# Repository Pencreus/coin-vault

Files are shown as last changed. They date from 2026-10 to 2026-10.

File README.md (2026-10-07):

# Coin Vault

3D-printable storage trays for copper bullion in Air-Tite capsules. Coins stand on
edge, face to face, in a curved cradle, and a sliding bookend keeps a part-full row
upright. Everything is parametric OpenSCAD and prints with no supports.

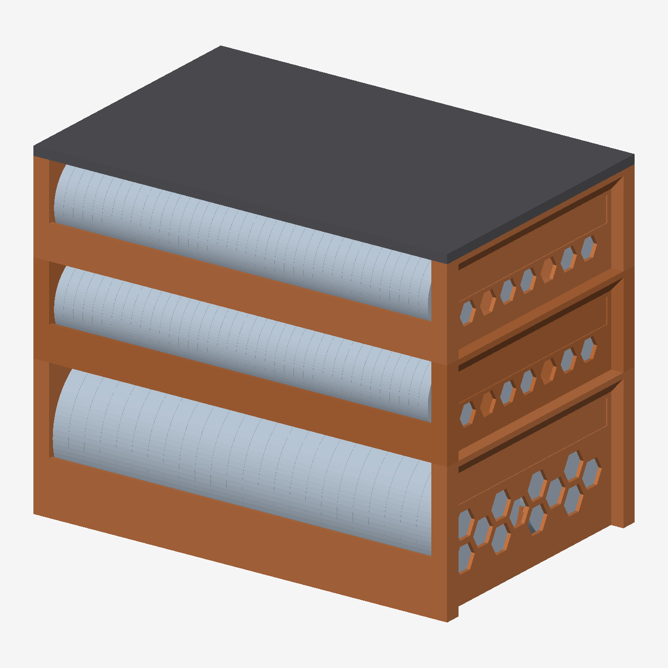
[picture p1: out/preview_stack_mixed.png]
Mixed stack: one 5 oz tray, two 1 oz trays, one lid


## Parts

| File | Holds | Size (mm) | PLA |
|---|---|---|---|
| `coin_vault_tray_Y63.stl` | 48 × 5 oz rounds in Air-Tite **Y63** (Ø71.37 × 8.9) | 233 × 151 × 77 | ~210 g |
| `coin_vault_tray_H39.stl` | 117 × 1 oz rounds in Air-Tite **H39** (Ø44.45 × 5.4) | 233 × 151 × 50 | ~175 g |
| `coin_vault_tray_NICKEL.stl` | 175 × Buffalo nickels in Ø25.5 capsules (5 rows) | 233 × 151 × 31.5 | ~155 g |
| `coin_vault_tray_HALF.stl` | 105 × half dollars in Ø35.3 capsules (3 rows) | 233 × 151 × 41 | ~165 g |
| `coin_vault_tray_MIXED.stl` | 35 nickels (front row) + 105 half dollars (3 rows) | 233 × 151 × 41 | ~170 g |
| `coin_vault_lid.stl` | caps any stack | 233 × 151 × 5 | ~95 g |
| `coin_vault_bookend_Y63.stl` / `_H39.stl` / `_NICKEL.stl` / `_HALF.stl` | one per part-full row | | 1–10 g |
| `slab_tray.stl` | 52 × 90 × 60 mm 5 oz slab capsules (7–8 mm thick), portrait | 233 × 151 × 55 | ~160 g |
| `slab_bookend.stl` | one per part-full row | | ~12 g |

Gram figures are estimates at 15% infill; your slicer has the final word. Nickel and half-dollar
counts assume 6 mm capsules; capsules stand face to face, so thinner ones simply fit more per row.

**Coin trays stack.** The 5 oz, 1 oz, nickel, half-dollar and mixed trays share one footprint
and corner-post pattern, so they mix freely in a stack under the same lid. Tapered pins on the posts
locate each tray, and each tray's floor closes the one below it. The slab tray is a
tray with carry handles and the same footprint. Sockets in its four corner feet take the coin
trays' pins, so it can sit on top of any coin tray in place of the lid. Nothing stacks on
top of it.

## Customizing

Open `coin_vault.scad` or `slab_tray.scad` in OpenSCAD and use **Window → Customizer**.
Keep `patterns.scad` in the same folder, because both files include it.

- `coin_vault.scad`: `capsule` (Y63 / H39 / NICKEL / HALF / MIXED), `part` (tray / lid / bookend / preview),
  rows and capsules per row (0 = as many as fit), clearances, end-wall opening pattern.
- `slab_tray.scad`: `footprint` (match the coin trays, or size from rows), `orientation`
  (portrait / landscape), `slab_t` (capsule thickness, default 8 mm), side and end wall heights.

Export with the Manifold backend (the default in current OpenSCAD).

## Strength

A full 5 oz tray holds about 8.7 kg. On a shelf the floor is supported everywhere. In a
stack, or when you lift it by the handles, the floor has to span about 217 mm between
the end walls. `sag_check.py` models that case conservatively: PLA long-term creep
modulus at E/3, sparse infill counted at 5% stiffness.

```
python sag_check.py Y63    # 5 oz: 0.96 mm worst case vs 1.85 mm clearance
python sag_check.py H39    # 1 oz: 0.73 mm worst case
python sag_check.py NICKEL # 0.66 mm;  HALF: 0.49 mm
```

These results set the design rules. Don't relax them to save filament:

- **Long walls stay solid.** Lattice openings in them made stacked sag 2.6× worse to
  save about 13 g.
- **The cradle floor is 3 mm thick at its lowest point.** At 1.2 mm the thin centre
  line acts as a hinge across the row.
- **Corner posts:** a 6-high stack of 5 oz trays stays at 4× their buckling margin.

## Printing

- PLA. It creeps less than PETG at room temperature. Keep it out of hot garages and
  attics, because PLA softens well below 60 °C.
- 15%+ infill (the cradle's stiffness depends on it), 0.2 mm layers, no supports.
- Print trays and the lid as modelled. Bookends print flat on their plate.
- End-wall openings are flat-top hexagons (short bridges only). Other patterns are in
  `patterns.scad`: diamond and teardrop are bridge-free, and X-brace is kept for
  reference only, since its triangle tops print badly.
- Store stacks on a solid shelf, not wire shelving.

## Files

- `coin_vault.scad`: stacking coin trays, lid, bookends
- `slab_tray.scad`: slab tray and bookend
- `patterns.scad`: shared wall-opening patterns
- `sag_check.py`: conservative stiffness check (numpy)
- `render.py`: tiny z-buffer STL preview renderer (numpy, trimesh, pillow)
- `out/`: exported STLs and preview images

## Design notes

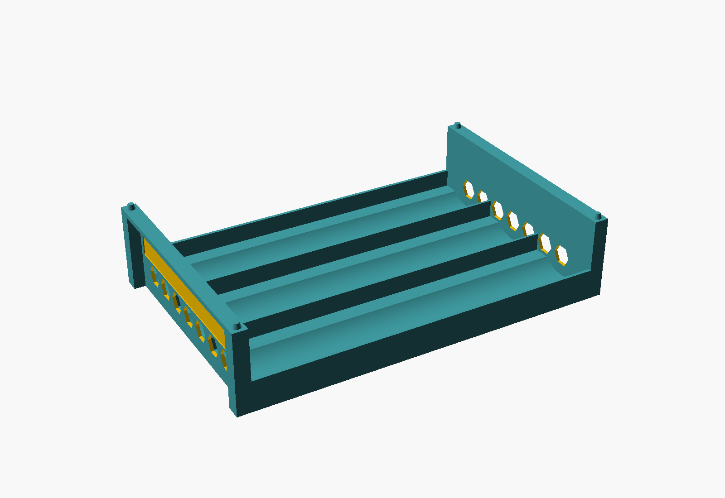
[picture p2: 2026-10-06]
out/preview_tray_H39.png

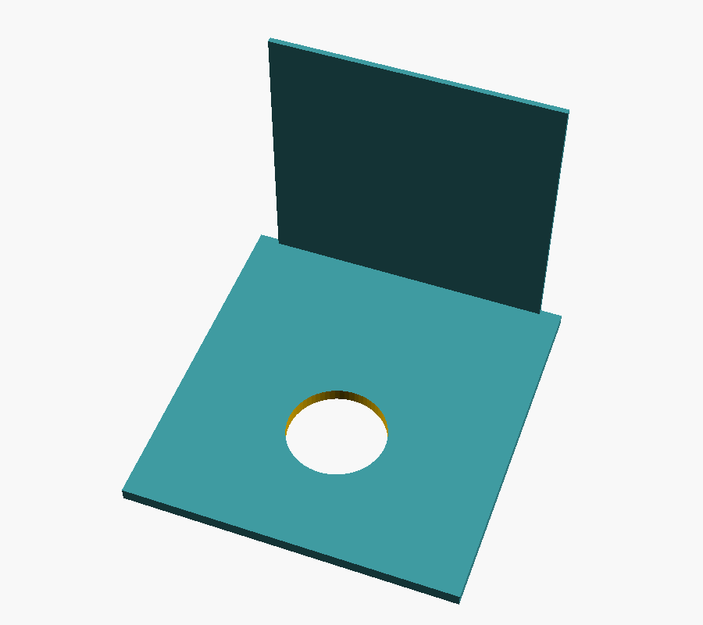
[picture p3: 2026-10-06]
out/preview_slab_bookend.png

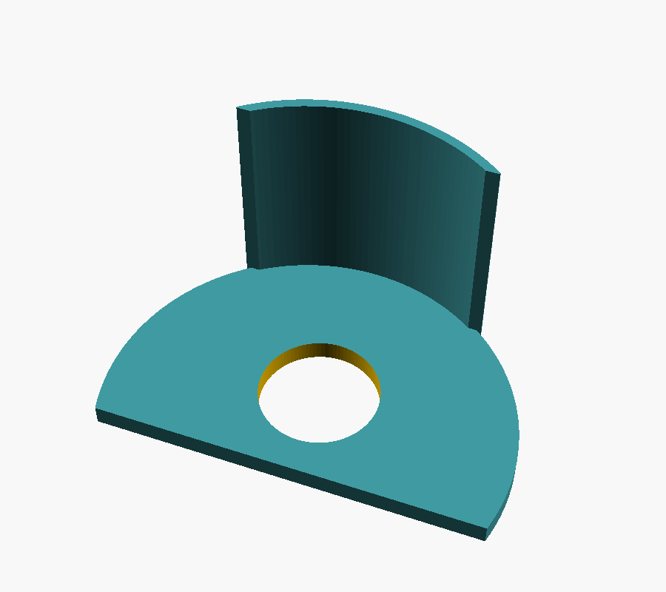
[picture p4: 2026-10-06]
out/preview_bookend_H39.png

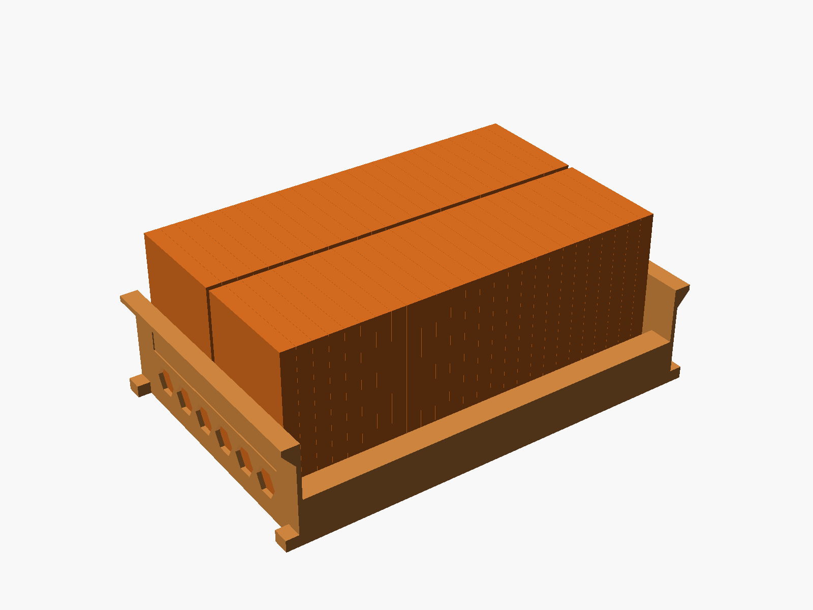
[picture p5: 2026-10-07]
out/preview_slab_loaded.png

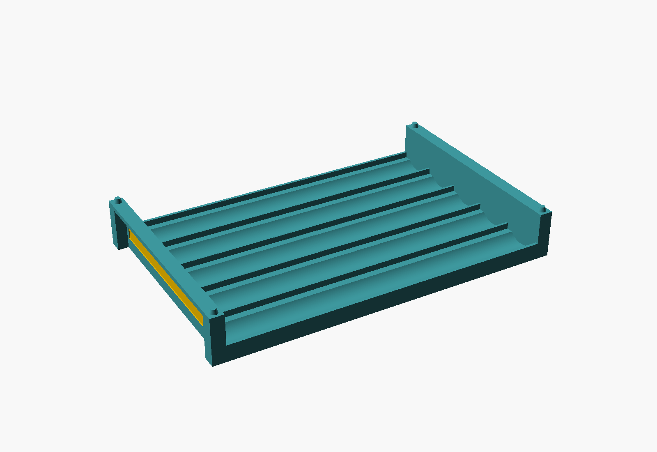
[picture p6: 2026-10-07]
out/preview_tray_NICKEL.png

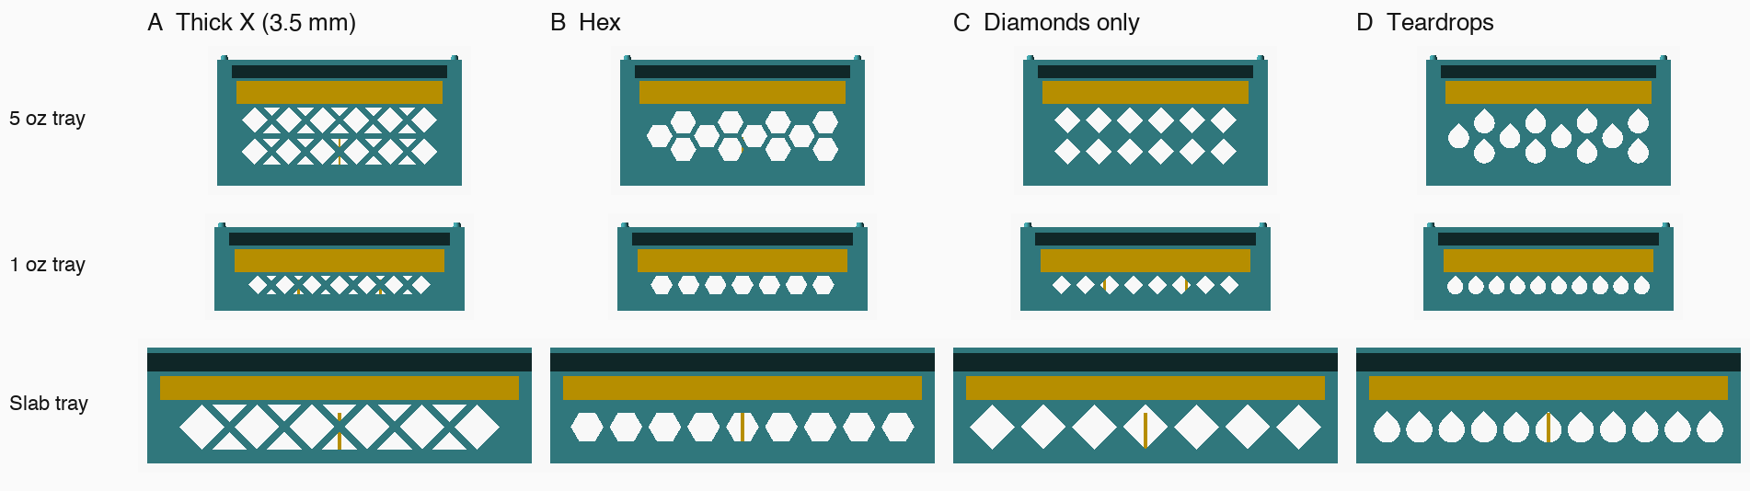
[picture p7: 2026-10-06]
out/pattern_compare.png

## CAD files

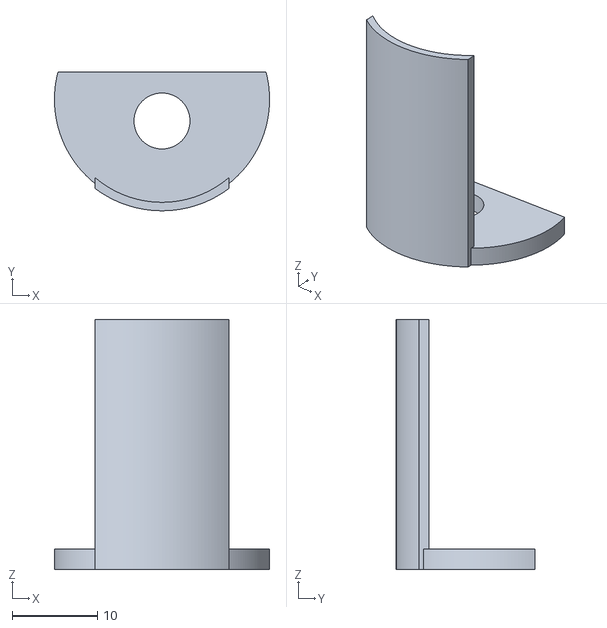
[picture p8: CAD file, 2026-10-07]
out/coin_vault_bookend_NICKEL.stl
25.3 x 16.3 x 29.4

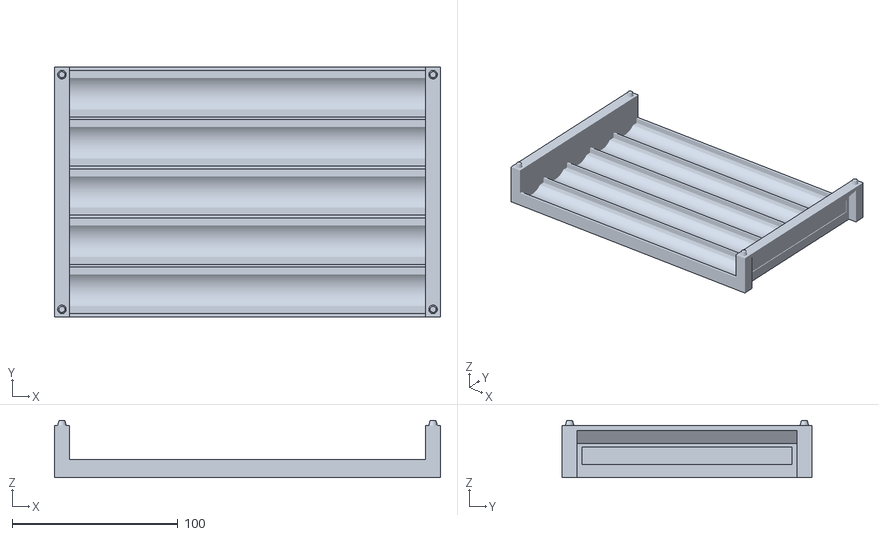
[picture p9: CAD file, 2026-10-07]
out/coin_vault_tray_NICKEL.stl
233.1 x 150.7 x 34.5

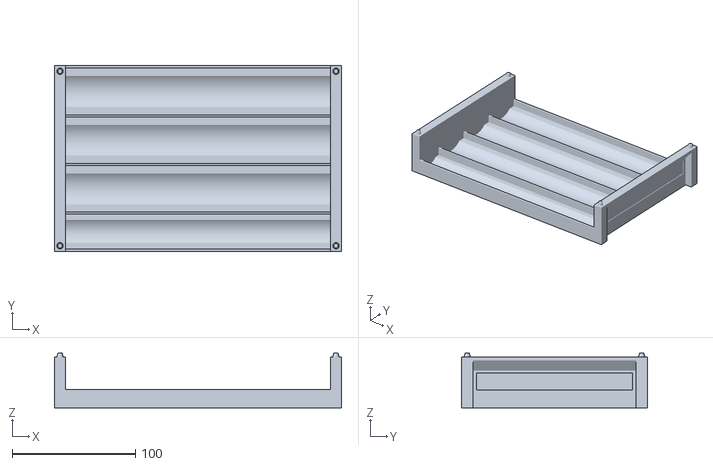
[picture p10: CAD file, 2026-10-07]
out/coin_vault_tray_MIXED.stl
233.1 x 150.7 x 44.3

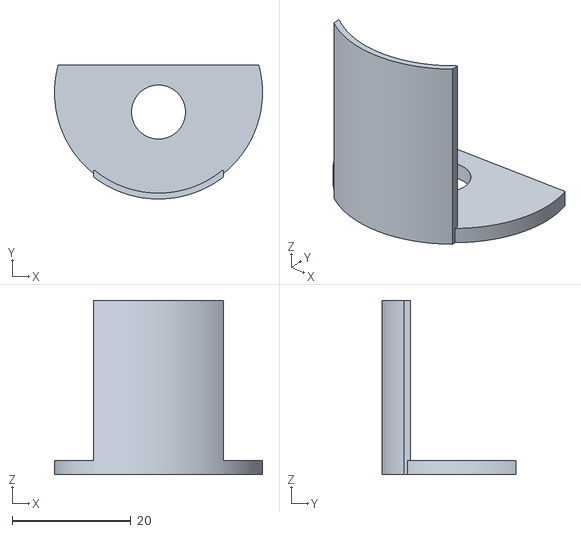
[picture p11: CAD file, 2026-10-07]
out/coin_vault_bookend_HALF.stl
35.1 x 22.6 x 29.4

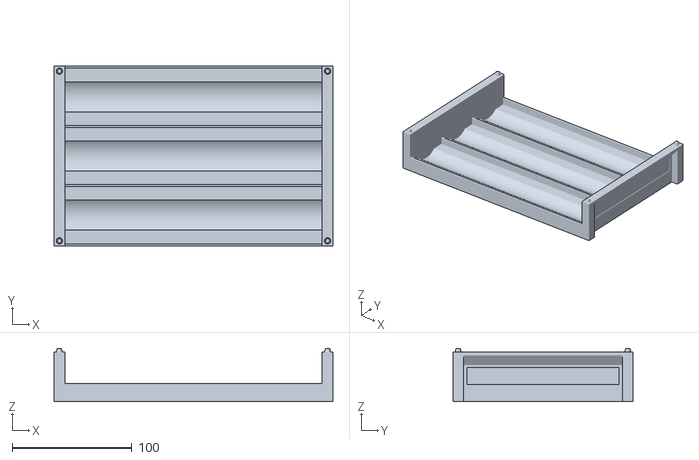
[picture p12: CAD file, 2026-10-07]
out/coin_vault_tray_HALF.stl
233.1 x 150.7 x 44.3

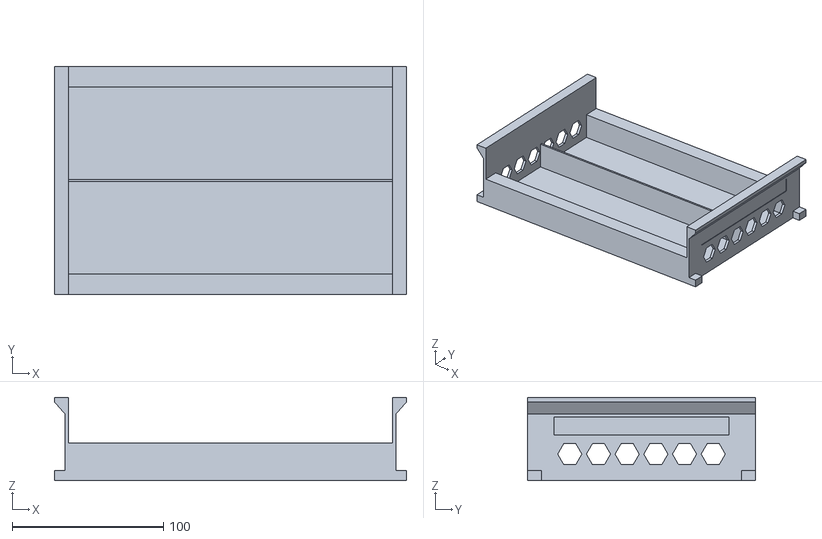
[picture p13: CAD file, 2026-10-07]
out/slab_tray.stl
233.1 x 150.7 x 55.0

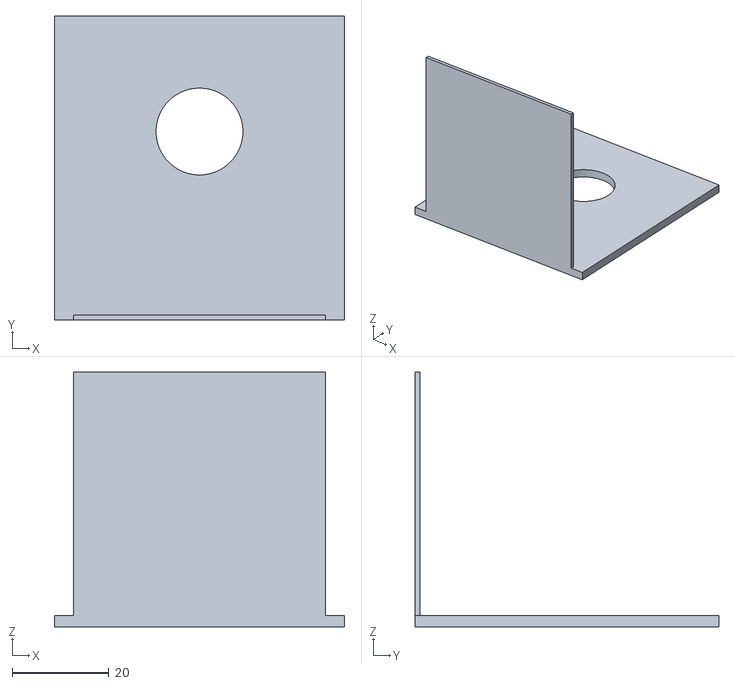
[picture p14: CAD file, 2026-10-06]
out/slab_bookend.stl
60.2 x 63.0 x 52.8

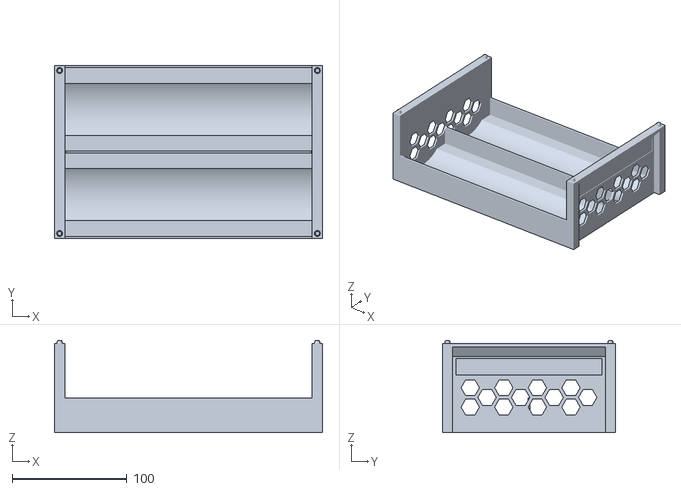
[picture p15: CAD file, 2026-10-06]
out/coin_vault_tray_Y63.stl
233.1 x 150.7 x 80.4

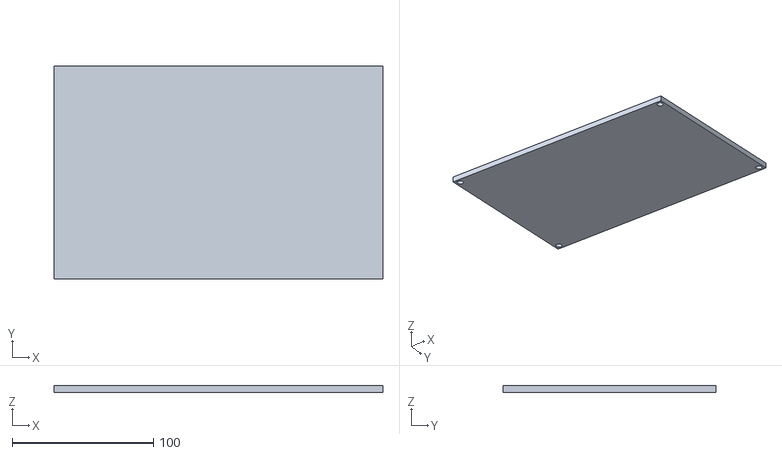
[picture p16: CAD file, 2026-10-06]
out/coin_vault_lid.stl
233.1 x 150.7 x 5.00

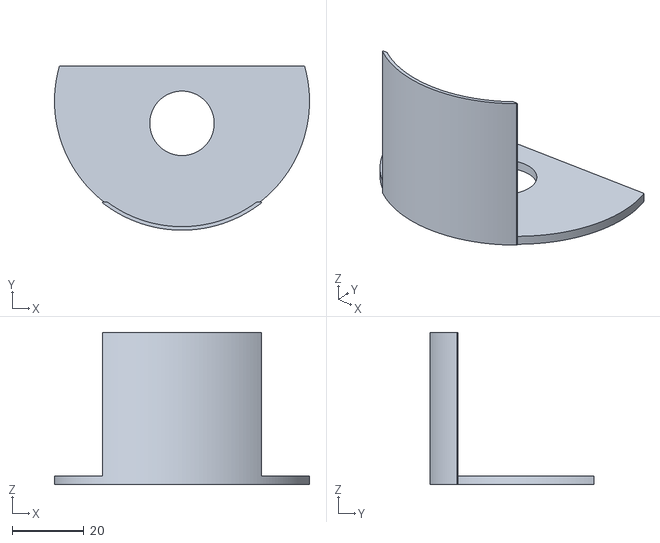
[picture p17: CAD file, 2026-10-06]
out/coin_vault_bookend_Y63.stl
71.2 x 45.9 x 42.5

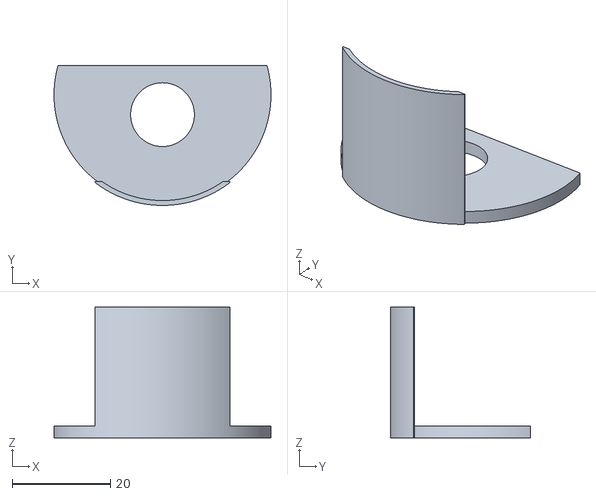
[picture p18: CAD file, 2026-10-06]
out/coin_vault_bookend_H39.stl
44.2 x 28.5 x 26.7

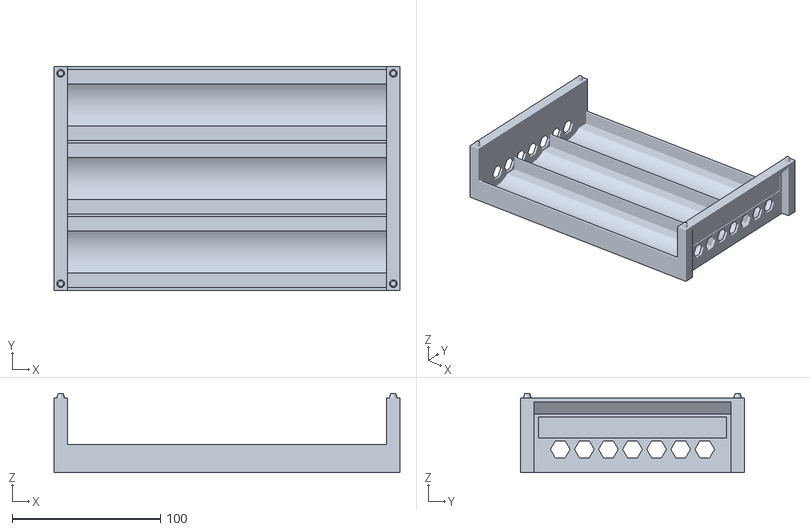
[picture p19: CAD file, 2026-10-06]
out/coin_vault_tray_H39.stl
233.1 x 150.7 x 53.4

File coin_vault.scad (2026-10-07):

// Coin Vault: stackable trays for Air-Tite capsules: Y63 (5 oz rounds) and H39 (1 oz).
// Every capsule type shares one footprint and post pattern, so 1 oz and 5 oz trays
// stack together under the same lid.
// Capsules stand on edge, face to face, in a curved cradle. A sliding bookend
// holds a part-full row upright. Trays stack on corner posts with tapered pins,
// and each tray's floor is the lid of the one below.
// Axes: X = along a row, Y = across rows, Z = up. Prints as modelled, no supports.

/* [Part] */
part = "tray"; // [tray, lid, bookend, preview_stack]

/* [Capsule] */
capsule = "Y63"; // [Y63:Y63 - 5 oz rounds, H39:H39 - 1 oz rounds, NICKEL:Nickel capsules (25.5 mm), HALF:Half dollar capsules (35.3 mm), MIXED:Mixed - 1 row of nickels + 3 rows of halves]

/* [Layout] */
footprint = "shared"; // [shared:Shared - stacks with every other tray, custom:Custom - sized from rows x per_row]
rows = 0;        // [0:1:6] 0 = as many as fit
per_row = 0;     // [0:1:45] 0 = as many as fit
row_clr = 1.5;   // minimum slack along a full row
clr_d = 1.2;     // row clearance, across the capsule diameter
top_clr = 3.0;   // gap above the capsule to the next tray's floor (sag margin)

/* [Structure] */
floor_t = 3.0;   // under the lowest point of the cradle. Do not thin: see sag_check.py
cradle_clr = 0.5;// cradle radius over the capsule radius
side = 2.0;      // long side walls
// side_h and cradle_h come from the capsule preset below
spine = 1.6;     // divider between rows
end_t = 2.0;     // end walls, full height
post = 9;        // square corner post
ledge_t = 3;     // handle ledge flange (45 deg gusset below)
label_d = 0.6;   // recessed label panel depth
lid_t = 5.0;     // flat slab; sockets are 3.5 deep, leaving a 1.5 mm roof over them

/* [Wall openings] */
end_pattern = "hex"; // [hex, diamond, teardrop, xbrace, solid] end walls (see patterns.scad)
web = 3.0;       // minimum material between openings
cell = 16;       // nominal opening size
wall_pattern = "solid"; // [solid, hex, diamond, teardrop, xbrace] long walls + spine. Openings here
                         // make a stacked tray sag ~2.6x more (sag_check.py) to save ~13 g: keep solid
strut = 2.0;     // solid band above the cradle before any opening
chord = 4;       // solid rail along the top of each wall
end_solid = 14;  // solid wall length next to each end (highest shear)
label_h = 14;    // label strip height, in the solid band under the ledge

/* [Bookend] */
book_t = 2.4;    // plate thickness
foot_t = 1.0;    // curved foot the capsules stand on

/* [Stacking pins] */
pin_h = 3;
pin_r0 = 2.6;
pin_r1 = 1.8;
sock_clr = 0.25;

/* [Hidden] */
include <patterns.scad>
$fn = 96;
eps = 0.01;

// Capsule presets. Air-Tite specs: Y63 = 71.37 OD x 8.9 closed; H39 = 44.45 OD x 5.4 closed.
//              cap_d  cap_t  side_h  cradle_h
PRESETS = [["Y63",    71.37, 8.9,  30,     8],
           ["H39",    44.45, 5.4,  19,     5],
           // Dad's generic capsules, measured: OD only. cap_t (6 mm) only sets the count and
           // preview: capsules stand face to face, so thinner ones just fit more per row.
           ["NICKEL", 25.5,  6.0,  11,     4],
           ["HALF",   35.3,  6.0,  15,     5],
           // MIXED: a row of nickels + 3 rows of halves (lanes below). Values are the halves'
           // (the tallest capsule sets the tray height and end walls).
           ["MIXED",  35.3,  6.0,  15,     5]];
P = PRESETS[search([capsule], PRESETS)[0]];
cap_d = P[1];
cap_t = P[2];
side_h = P[3];   // ~42% of the capsule: low enough to grip a rim from the side
cradle_h = P[4];

// The shared footprint is the 5 oz tray's: 2 rows x 24 Y63 capsules.
FOOT_L_IN = 24 * 8.9 + 1.5;
FOOT_W = 2 * (71.37 + 1.2) + 1.6 + 2 * 2.0;
R = cap_d / 2;
Rc = R + cradle_clr;
fit_rows = floor((FOOT_W - 2 * side + spine) / (cap_d + clr_d + spine) + 1e-6);
fit_per_row = floor((FOOT_L_IN - row_clr) / cap_t + 1e-6);
n_rows = rows > 0 ? rows : fit_rows;
n_per_row = per_row > 0 ? per_row : fit_per_row;
shared = footprint == "shared";
// shared: spare width goes into row clearance (the cradle still centres each capsule)
row_w = shared ? (FOOT_W - 2 * side - (n_rows - 1) * spine) / n_rows : cap_d + clr_d;
l_in = shared ? FOOT_L_IN : n_per_row * cap_t + row_clr;
W = shared ? FOOT_W : n_rows * row_w + (n_rows - 1) * spine + 2 * side;
H = floor_t + cap_d + top_clr;
assert(!shared || (n_rows <= fit_rows && n_per_row <= fit_per_row), "too many capsules for the shared footprint");

// MIXED lanes, front to back: [lane's capsule, [[cap_d, cap_t, cradle_h, from, to]]] (from/to = share of the row)
// Nickels at the front edge, so their low rims can be pushed up from the side.
mixed = capsule == "MIXED";
MIX = [[25.5, [[25.5, 6.0, 4, 0, 1]]],
       [35.3, [[35.3, 6.0, 5, 0, 1]]],
       [35.3, [[35.3, 6.0, 5, 0, 1]]],
       [35.3, [[35.3, 6.0, 5, 0, 1]]]];
function lsum(v, i = 0) = i >= len(v) ? 0 : v[i] + lsum(v, i + 1);
mix_spare = (FOOT_W - 2 * side - (len(MIX) - 1) * spine - lsum([for (l = MIX) l[0] + clr_d])) / len(MIX);
assert(!mixed || mix_spare >= 0, "MIXED lanes don't fit the shared footprint");
function lane_w(i) = MIX[i][0] + clr_d + mix_spare;
function lane_y0(i) = side + (i == 0 ? 0 : lane_y0(i - 1) - side + lane_w(i - 1) + spine);
divider = 2.0;   // fixed wall between the two halves of the split row
function seg_x0(f) = X0 + end_t + f * l_in + (f > 0 ? divider / 2 : 0);
function seg_x1(f) = X0 + end_t + f * l_in - (f < 1 ? divider / 2 : 0);
function seg_n(sg) = floor((seg_x1(sg[4]) - seg_x0(sg[3]) - 1.0) / sg[1] + 1e-6);

// bookend scales with the capsule
foot_l = max(24, 4.5 * cap_t);   // ~4.5 capsules stand on the foot and hold it down
foot_w = 0.62 * cap_d;
plate_h = 0.645 * cap_d;
out_ = post - end_t;          // how far posts stand proud of the end walls
X0 = 0;
X1 = l_in + 2 * end_t;

function row_y0(r) = side + r * (row_w + spine);
function row_yc(r) = row_y0(r) + row_w / 2;
corners = [for (x = [X0 - out_, X1 + out_ - post]) for (y = [0, W - post]) [x, y]];

module box(a, b) translate(a) cube(b - a);

// 2D (x, z) shape extruded along Y from y0 to y1. Exact matrix, no rotate().
module xz_extrude(y0, y1) multmatrix([[1, 0, 0, 0], [0, 0, 1, y0], [0, 1, 0, 0]]) linear_extrude(y1 - y0) children();
// 2D (y, z) shape extruded along X from x0 to x1.
module yz_extrude(x0, x1) multmatrix([[0, 0, 1, x0], [1, 0, 0, 0], [0, 1, 0, 0]]) linear_extrude(x1 - x0) children();

module pin() cylinder(h = pin_h, r1 = pin_r0, r2 = pin_r1);
module socket()
    translate([0, 0, -eps])
        cylinder(h = pin_h + 0.5 + eps, r1 = pin_r0 + sock_clr, r2 = pin_r1 + sock_clr - 0.1);

// ---- wall lattice: 2D holes in the (x, z) plane of a long wall ----
lat_x0 = X0 + end_t + end_solid;
lat_x1 = X1 - end_t - end_solid;
lat_z0 = floor_t + cradle_h + strut;   // bottom chord = cradle + one strut
lat_z1 = side_h - chord;

// End walls: openings between the posts, from the cradle up to a solid top band
// that carries the label strip and the handle ledge.
label_z1 = H - ledge_t - out_ - 3;
label_z0 = label_z1 - min(label_h, label_z1 - (floor_t + cradle_h + 1));   // shorter trays: the strip shrinks to fit
end_v0 = floor_t + cradle_h + strut;
end_v1 = label_z0 - strut;
end_open = end_v1 - end_v0 >= 8;                      // too short a band for openings: leave the wall solid
module end_holes() if (end_open) wall_pattern_2d(end_pattern, post + web, W - post - web, end_v0, end_v1, web, cell);

module lattice_cut(y0, y1)
    if (wall_pattern != "solid") xz_extrude(y0 - 1, y1 + 1) wall_pattern_2d(wall_pattern, lat_x0, lat_x1, lat_z0, lat_z1, web, cell);

// Cradle under one row: a block up to cradle_h with the capsule arc cut out.
// The capsule's lowest point lands at floor_t.
module cradle(yc)
    yz_extrude(X0 + end_t - eps, X1 - end_t + eps)
        difference() {
            translate([yc - row_w / 2 - eps, 0]) square([row_w + 2 * eps, floor_t + cradle_h]);
            translate([yc, floor_t + Rc]) circle(Rc, $fn = 192);
        }

module ledge(xw, sgn) {
    // 3 mm flange flush with the posts, 45 deg gusset underneath. Built with a 3D
    // hull, not a 2D polygon: OpenSCAD snaps 2D to a fixed grid, which leaves the
    // top a hair off the post tops and the STL comes out non-manifold.
    xi = xw - sgn * 1;    // 1 mm into the end wall
    y0 = post / 2; y1 = W - post / 2;
    hull() {
        box([min(xi, xw + sgn * out_), y0, H - ledge_t], [max(xi, xw + sgn * out_), y1, H]);
        box([min(xi, xw), y0, H - ledge_t - out_ - 1], [max(xi, xw), y1, H]);
    }
}

module seg_cradle(y0, w, d, ch, x0, x1)
    yz_extrude(x0 - eps, x1 + eps)
        difference() {
            translate([y0 - eps, 0]) square([w + 2 * eps, floor_t + ch]);
            translate([y0 + w / 2, floor_t + d / 2 + cradle_clr]) circle(d / 2 + cradle_clr, $fn = 192);
        }
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

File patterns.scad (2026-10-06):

// Wall opening patterns for Coin Vault parts. Every pattern is a set of 2D holes
// in a (u, v) zone: u runs along the wall, v is up (the print's Z), so overhangs
// are judged against v. Shared by coin_vault.scad and slab_tray.scad.
//
//   xbrace   : diamonds + triangles (Warren truss). Triangle tops are flat bridges.
//   hex      : flat-top honeycomb. Tops are short bridges (one hex side).
//   diamond  : diamonds only, 45 deg everywhere, no bridges at all.
//   teardrop : round holes with a 45 deg point on top, no bridges.
//   solid    : nothing.

// X-brace (Warren) truss: a row of diamonds with triangles between them.
module pat_xbrace_row(u0, u1, v0, v1, web) {
    a = (v1 - v0) / 2;
    vc = v0 + a;
    p = 2 * a + web * sqrt(2);
    n = floor((u1 - u0 - 2 * a) / p) + 1;
    uc = (u0 + u1) / 2 - (n - 1) * p / 2;
    d = web / sqrt(2);
    for (i = [0:n - 1]) translate([uc + i * p, vc]) polygon([[a, 0], [0, a], [-a, 0], [0, -a]]);
    for (i = [0:n - 2]) let(um = uc + (i + 0.5) * p, w = a - d) {
        polygon([[um, vc + d], [um + w, vc + a], [um - w, vc + a]]);
        polygon([[um, vc - d], [um - w, vc - a], [um + w, vc - a]]);
    }
}

// Diamonds only: the web between neighbours is narrowest (= web) at mid-height.
module pat_diamond_row(u0, u1, v0, v1, web) {
    a = (v1 - v0) / 2;
    vc = v0 + a;
    p = 2 * a + web;
    n = floor((u1 - u0 - 2 * a) / p) + 1;
    uc = (u0 + u1) / 2 - (n - 1) * p / 2;
    for (i = [0:n - 1]) translate([uc + i * p, vc]) polygon([[a, 0], [0, a], [-a, 0], [0, -a]]);
}

// Rows stacked with a solid web between tiers, so struts stay short on tall walls.
module pat_tiers(u0, u1, v0, v1, web, cell, kind) {
    tiers = max(1, round((v1 - v0) / cell));
    th = (v1 - v0 - (tiers - 1) * web) / tiers;
    for (k = [0:tiers - 1]) let(t0 = v0 + k * (th + web)) {
        if (kind == "xbrace") pat_xbrace_row(u0, u1, t0, t0 + th, web);
        else pat_diamond_row(u0, u1, t0, t0 + th, web);
    }
}

// Staggered grid of a cell shape of half-width hw and half-height hh, only whole cells.
module pat_grid(u0, u1, v0, v1, hw, hh, dx, dz) {
    nx = floor((u1 - u0 - 2 * hw) / dx) + 1;
    us = (u0 + u1) / 2 - (nx - 1) * dx / 2;
    nz = floor((v1 - v0 - 2 * hh) / dz) + 1;          // rows that fit unstaggered
    vs = (v0 + v1) / 2 - (nz - 1) * dz / 2;
    stag = (v1 - v0) >= 2 * hh + dz / 2 + 0.01;       // room for an offset row?
    for (i = [0:nx - 1], j = [0:nz - 1])
        let(u = us + i * dx, v = vs + j * dz + (stag && i % 2 == 1 ? dz / 2 : 0))
            if (v - hh >= v0 - 0.01 && v + hh <= v1 + 0.01) translate([u, v]) children();
}

module hex_cell(r) circle(r, $fn = 6);       // vertex at +u: flat top and bottom
module teardrop_cell(r) hull() { circle(r, $fn = 48); translate([0, r * sqrt(2)]) square(0.01, center = true); }

module wall_pattern_2d(kind, u0, u1, v0, v1, web, cell) {
    if (kind == "xbrace" || kind == "diamond") pat_tiers(u0, u1, v0, v1, web, cell, kind);
    else if (kind == "hex") {
        r = min(cell / 2, (v1 - v0) / sqrt(3));
        R = r + web / sqrt(3);
        hh = sqrt(3) / 2 * r;
        stag = (v1 - v0) >= 2 * hh + sqrt(3) * R / 2;
        // honeycomb spacing when columns can stagger, else a single row side by side
        pat_grid(u0, u1, v0, v1, r, hh, stag ? 1.5 * R : 2 * r + web, sqrt(3) * R) hex_cell(r);
    }
    else if (kind == "teardrop") {
        r = min(cell / 2 * 0.8, (v1 - v0) / (1 + sqrt(2)));
        hh = r * (1 + sqrt(2)) / 2;                    // cell spans -r .. r*sqrt2 about its centre
        pat_grid(u0, u1, v0, v1, r, hh, 2 * r + web, 2 * hh + web)
            translate([0, -(r * sqrt(2) - r) / 2]) teardrop_cell(r);
    }
}

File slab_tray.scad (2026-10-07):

// Coin Vault: slab tray for 90 x 60 mm copper slabs (5 oz).
// Slabs stand on their long edge, face to face, like files. A sliding bookend
// holds a part-full row upright. Not a stacking part: no posts, pins or lid.
// Axes: X = along a row (slab faces point along X), Y = across rows, Z = up.
// Prints as modelled, no supports.

/* [Part] */
part = "tray"; // [tray, bookend, preview]

/* [Slab] */
slab_long = 90;  // capsule outside size
slab_short = 60;
orientation = "portrait"; // [portrait:Portrait - stands on the 60 edge, 90 tall, landscape:Landscape - stands on the 90 edge, 60 tall]
slab_t = 8.0;    // capsule thickness: typical 5 oz slab capsules are 7-8 mm; 8 fits both
slab_g = 155.5;  // weight, for the echo only

/* [Layout] */
footprint = "match coin trays"; // [match coin trays:Match the 1 oz / 5 oz trays (233.1 x 150.7), fit:Sized from rows x per_row]
rows = 2;        // [1:1:3]
per_row = 0;     // [0:1:80] 0 = as many as fit (match: 26 at 8 mm)
row_clr = 2.0;   // minimum slack along a full row
clr_w = 1.2;     // clearance across the row

/* [Structure] */
floor_t = 3.0;   // only loaded while carried by the handles: 0.29 mm then (2.4 mm would be 0.52)
side_min = 2.0;  // long side walls (match mode: spare width goes into these, making thick rigid sides)
side_h = 25;     // low enough to push a slab up by its side edge
end_h = 55;      // end walls only stop the end slab tipping (this tray doesn't stack)
spine = 1.6;     // divider between rows
end_t = 2.4;     // end walls, carry the load when lifted by the handles
handle = 7;      // handle ledge depth, 45 deg gusset underneath (7 = the coin trays' post depth)
ledge_t = 3;
label_d = 0.6;
label_h = 12;
strut = 2.0;     // solid band above the floor before any opening
end_pattern = "hex"; // [hex, diamond, teardrop, xbrace, solid] end walls (see patterns.scad)
web = 3.0;       // minimum material between openings
cell = 16;       // nominal opening size

/* [Stacking] */
sits_on_coin_trays = true; // corner feet with sockets so this tray sits on a 1 oz / 5 oz tray (match footprint only)
foot_post = 9;   // the coin trays' corner post (square)
foot_h = 6.5;    // socket 3.5 deep + 3 mm roof
pin_h = 3;       // the coin trays' tapered pins...
pin_r0 = 2.6;
pin_r1 = 1.8;
sock_clr = 0.25; // ...and the same socket clearance the lid uses

/* [Bookend] */
book_t = 2.4;
foot_t = 1.0;
foot_slabs = 6;  // slabs that stand on the foot and hold it down

/* [Hidden] */
include <patterns.scad>
eps = 0.01;
slab_w = orientation == "portrait" ? slab_short : slab_long;   // edge it stands on
slab_h = orientation == "portrait" ? slab_long : slab_short;   // standing height
row_w = slab_w + clr_w;
// the coin trays' outline: 24 x 8.9 + 1.5 inside, 2 mm end walls, 7 mm posts; 2 rows of 72.57 + 1.6 + 2 x 2
FOOT_X = 24 * 8.9 + 1.5 + 2 * 2.0 + 2 * 7;
FOOT_Y = 2 * (71.37 + 1.2) + 1.6 + 2 * 2.0;
match = footprint == "match coin trays";
l_in = match ? FOOT_X - 2 * end_t - 2 * handle : per_row * slab_t + row_clr;
n_per_row = per_row > 0 ? per_row : floor((l_in - row_clr) / slab_t + 1e-6);
W = match ? FOOT_Y : rows * row_w + (rows - 1) * spine + 2 * side_min;
side = (W - rows * row_w - (rows - 1) * spine) / 2;
H = end_h;
assert(side >= side_min - 1e-6, "rows don't fit the coin-tray footprint");
assert(n_per_row * slab_t + row_clr <= l_in + 1e-6, "too many slabs for the row length");
X0 = 0;
X1 = l_in + 2 * end_t;

function row_y0(r) = side + r * (row_w + spine);
function row_yc(r) = row_y0(r) + row_w / 2;

module box(a, b) translate(a) cube(b - a);
module yz_extrude(x0, x1) multmatrix([[0, 0, 1, x0], [1, 0, 0, 0], [0, 1, 0, 0]]) linear_extrude(x1 - x0) children();

label_z1 = H - ledge_t - handle - 3;
label_z0 = label_z1 - label_h;
end_v0 = floor_t + strut + 2;
end_v1 = label_z0 - strut;
module end_holes() wall_pattern_2d(end_pattern, side + web, W - side - web, end_v0, end_v1, web, cell);

// Handle ledge: flange flush at the top, 45 deg gusset below. 3D hull, not a 2D
// polygon (OpenSCAD's 2D grid snapping breaks coplanar faces).
module ledge(xw, sgn) {
    xi = xw - sgn * 1;
    hull() {
        box([min(xi, xw + sgn * handle), 0, H - ledge_t], [max(xi, xw + sgn * handle), W, H]);
        box([min(xi, xw), 0, H - ledge_t - handle - 1], [max(xi, xw), W, H]);
    }
}

// coin-tray post positions: posts stand handle (=7) proud of each end wall, flush with the long sides
feet = [for (x = [X0 - handle, X1 + handle - foot_post]) for (y = [0, W - foot_post]) [x, y]];
module socket()
    translate([0, 0, -eps]) cylinder(h = pin_h + 0.5 + eps, r1 = pin_r0 + sock_clr, r2 = pin_r1 + sock_clr - 0.1, $fn = 64);

module tray() {
    spines = [for (r = [1:1:rows - 1]) row_y0(r) - spine];
    stack = sits_on_coin_trays && match;
    difference() {
        union() {
            if (stack) for (f = feet) box([f[0], f[1], 0], [f[0] + foot_post, f[1] + foot_post, foot_h]);
            box([X0, 0, 0], [X1, W, floor_t]);
            box([X0, 0, 0], [X1, side, side_h]);
            box([X0, W - side, 0], [X1, W, side_h]);
            for (y = spines) box([X0, y, 0], [X1, y + spine, side_h]);
            box([X0, 0, 0], [X0 + end_t, W, H]);
            box([X1 - end_t, 0, 0], [X1, W, H]);
            ledge(X0, -1);
            ledge(X1, 1);
        }
        if (end_pattern != "solid") {
            yz_extrude(X0 - 1, X0 + end_t + 1) end_holes();
            yz_extrude(X1 - end_t - 1, X1 + 1) end_holes();
        }
        if (stack) for (f = feet) translate([f[0] + foot_post / 2, f[1] + foot_post / 2, 0]) socket();
        box([X0 - 1, side + 4, label_z0], [X0 + label_d, W - side - 4, label_z1]);
        box([X1 - label_d, side + 4, label_z0], [X1 + 1, W - side - 4, label_z1]);
    }
}

// Sliding bookend in use position: plate face at x = 0, slabs on +X standing on
// the flat foot. Their weight pins it down.
module bookend_in_place() {
    bw = row_w - 1.0;
    plate_h = 0.7 * slab_h;
    foot_l = foot_slabs * slab_t + book_t;
    difference() {
        union() {
            box([-book_t, -bw / 2, floor_t], [0, bw / 2, floor_t + plate_h]);
            box([-book_t, -bw / 2 + 4, floor_t], [foot_l, bw / 2 - 4, floor_t + foot_t]);
        }
        // finger hole to slide it along
        translate([-book_t - 1, 0, floor_t + 0.62 * plate_h])
            multmatrix([[0, 0, 1, 0], [0, 1, 0, 0], [-1, 0, 0, 0]]) cylinder(h = book_t + 2, r = 9, $fn = 64);
    }
}

// Print orientation: plate flat on the bed, foot standing up.
module bookend() multmatrix([[0, 1, 0, 0], [0, 0, 1, -floor_t], [1, 0, 0, book_t]]) bookend_in_place();

module slabs(n)
    for (r = [0:rows - 1], i = [0:n - 1])
        translate([X0 + end_t + 0.3 + i * slab_t, row_yc(r) - slab_w / 2, floor_t + 0.05])
            cube([slab_t - 0.1, slab_w, slab_h]);

echo(str("slab tray: ", rows, " x ", n_per_row, " = ", rows * n_per_row, " slabs, ~",
         rows * n_per_row * (slab_g + 25) / 1000, " kg full (incl. capsules), tray ", X1 - X0 + 2 * handle, " x ", W,
         " x ", H, ", side walls ", side_h, " tall x ", side, " thick"));

if (part == "tray") tray();
else if (part == "bookend") bookend();
else {
    color("Peru") tray();
    color("Chocolate") slabs(n_per_row);
}

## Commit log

2026-10-06 Coin Vault: stackable trays for Air-Tite Y63 (5 oz) and H39 (1 oz) capsules, plus a slab tray
    - Shared footprint and post pattern, so 1 oz and 5 oz trays mix in one stack under one lid
    - Curved 3 mm cradle floor and solid long walls, sized by sag_check.py
    - Flat-top hex end-wall openings (X-brace triangle tops printed badly)
    - Portrait slab tray for 90 x 60 mm 5 oz slab capsules
    [coin_vault.scad, coin_vault_bookend_H39.stl, coin_vault_bookend_Y63.stl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]
2026-10-06 Slab tray: same footprint as the coin trays, lower walls, sized for 8 mm capsules
    - 233.1 x 150.7 mm (matches the 1 oz / 5 oz trays), 2 portrait rows x 26 = 52 slabs, ~9.4 kg full
    - End walls 87 -> 55 mm, side walls 38 -> 25 mm; spare width goes into 13.4 mm thick sides
    - slab_t 3.2 -> 8.0 (typical 7-8 mm capsules); carried full: 0.18 mm flex, floor 0.10 mm
    [slab_bookend.stl, slab_tray.scad, slab_tray.stl]
2026-10-07 Slab tray: corner feet with sockets so it sits on a 1 oz / 5 oz tray
    Same socket spec as the lid, at the coin trays' post positions. Verified seated on both coin
    trays with zero interference (overlap 0.0007 mm3 = mesh rounding).
    [slab_tray.scad, slab_tray.stl]
2026-10-07 Add Buffalo nickel, half dollar and mixed trays
    - NICKEL: 5 rows (Ø25.5 capsules), HALF: 3 rows (Ø35.3), MIXED: 1 nickel row + 3 half-dollar rows
    - Same footprint, posts and pins: all stack with the 5 oz / 1 oz trays, the lid and the slab tray
    (seat checks: zero interference in every combination)
    - Short trays: the label strip shrinks to fit and end-wall openings are skipped when there is no room
    - Existing trays, bookends and lid verified byte-identical
    [coin_vault.scad, coin_vault_bookend_HALF.stl, coin_vault_bookend_NICKEL.stl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]
2026-10-15 Add rectangular capsule tray (35.7 x 57.5, portrait)
    - RECT preset: 3 portrait rows x 30 = 90 (7 mm capsules), flat floor with a 3 mm locating
    channel per row, 24 mm side walls, matching flat bookend
    - Same footprint, posts and pins: seats on and under every tray, the lid and the slab tray
    with zero interference; stacked long-term sag ~0.3 mm (0.44 mm at 60 g per capsule)
    - All existing trays, bookends and the lid verified byte-identical
2026-11-10 Bookend track in every row, thicker outer walls (same footprint), stackable SLAB tray preset
    - stepped bookend track in each row's floor + matching tongue on every bookend; floor_t 4 (5 for SLAB)
    - long walls 2 -> 4 mm inward as far as the capsules allow; end walls 2 -> 5 mm outward below the handle ledge
    - new SLAB preset (93.3 x 62.5 x 5 and 90 x 60 x 8 slabs), sag_check.py handles rect/slab + groove
2026-11-10 Regenerate previews, release scripts (9-plate MakerWorld 3MF, Cults package), README for the SLAB tray, bookend track and thicker walls
